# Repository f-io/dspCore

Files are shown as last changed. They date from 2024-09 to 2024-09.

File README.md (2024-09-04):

# dspCore
Build arround the ADAU1452 / ADAU1462 / ADAU1466 from Analog Devices with balanced 2-in / 6-out as well as support for I2S, SPDIF and TDM. This board is optimized for low noise performance and in particular to support all features of the [ICEpower 300A1](https://shop.icepoweraudio.com/product/300a1/) and similary amplifier modules.<br>

First prototyp build in 2014, redesigned in 2016 and the lastest version in 2021, mostly to substetude conflict materials like tantalum. The I2S input was tested with RaspberryPi 3/4/5 and ESP32S3.

## Design requirements
 - Balanced  2-in / 6-out 
 - Low idle noise without active mute circuit (compression driver requirement @ >100dB/1W/1m)
 - Stereo 3-way active x-over with FIR support for mid-high
 - Flexible I2S interaface
 - 48V DC batterie operation

## Hardware
dspCore

- DSP:  [ADAU1466](https://www.analog.com/en/products/adau1466.html) or [ADAU1452](https://www.analog.com/en/products/adau1452.html)
- A/D:  [CS5381](https://www.cirrus.com/products/cs5381/)
- D/A:  [CS4389](https://www.cirrus.com/products/cs4398/)
- OPA:  [OPA1612](https://www.ti.com/product/de-de/OPA1612/part-details/OPA1612AID)
- XO:   [CCHD-957](https://www.crystek.com/home/oscillator/clockdetail.aspx?pn=CCHD-957)
- USB:  [CY7C68013A](https://www.infineon.com/cms/de/product/universal-serial-bus/usb-2.0-peripheral-controllers/ez-usb-fx2lp-fx2g2-usb-2.0-peripheral-controller/cy7c68013a-56ltxc/)

## Measurements
__The Poor Engineer's Distortion Analyzer__ is a distortion analyzer based on the idea of KJBob (@ ADI EngineeringZone).<br><br>
This is a loop back measurment (DSP->D/A->A/D->DSP), the result is therefore the performance of the full chain. The readings are close to the datasheet specifications of the CS4398, which makes us confident that we are measuring the right thing, but of course there is an uncertainty without external verification.<br>

### DUT
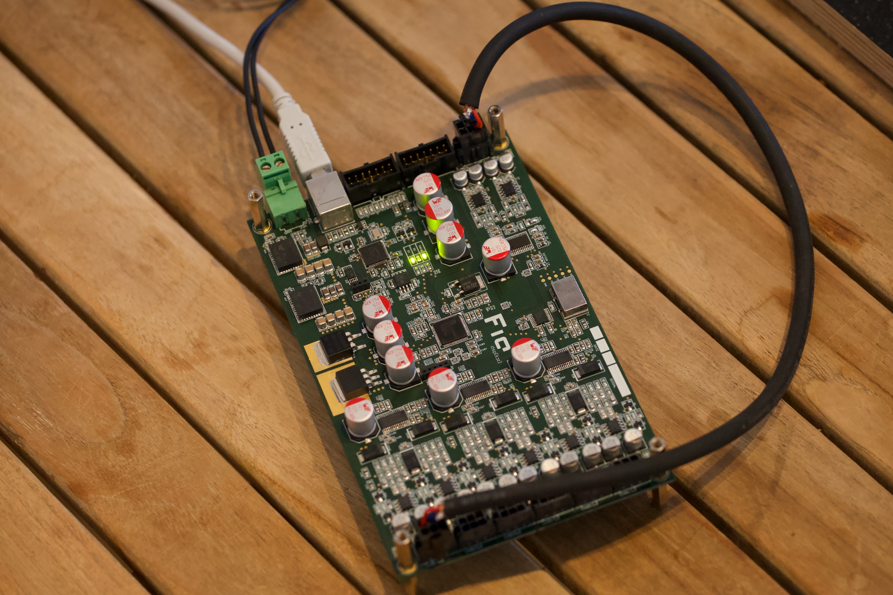
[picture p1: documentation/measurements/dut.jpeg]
dspCore
<br>

### 1V RMS
```0.000527918% THD+N = -105.54dB (a-weighted)```
<br><br>
![dspCore](documentation/measurements/1vrms_dspCore(diff)_thd+n.jpeg)<br>
### 2V RMS
```0.000626624% THD+N = -104.06dB (a-weighted)```
<br><br>
![dspCore](documentation/measurements/2vrms_dspCore(diff)_thd+n.jpeg)<br>

## To do

- Port eagle -> KiCad

## Usecase
![dspCore](documentation/images/tonkraftwerk.jpeg)<br>
![dspCore](documentation/images/tonkraftwerk_electronics.jpeg)<br>

## License

The hardware is licensed under CC BY-SA 4.0

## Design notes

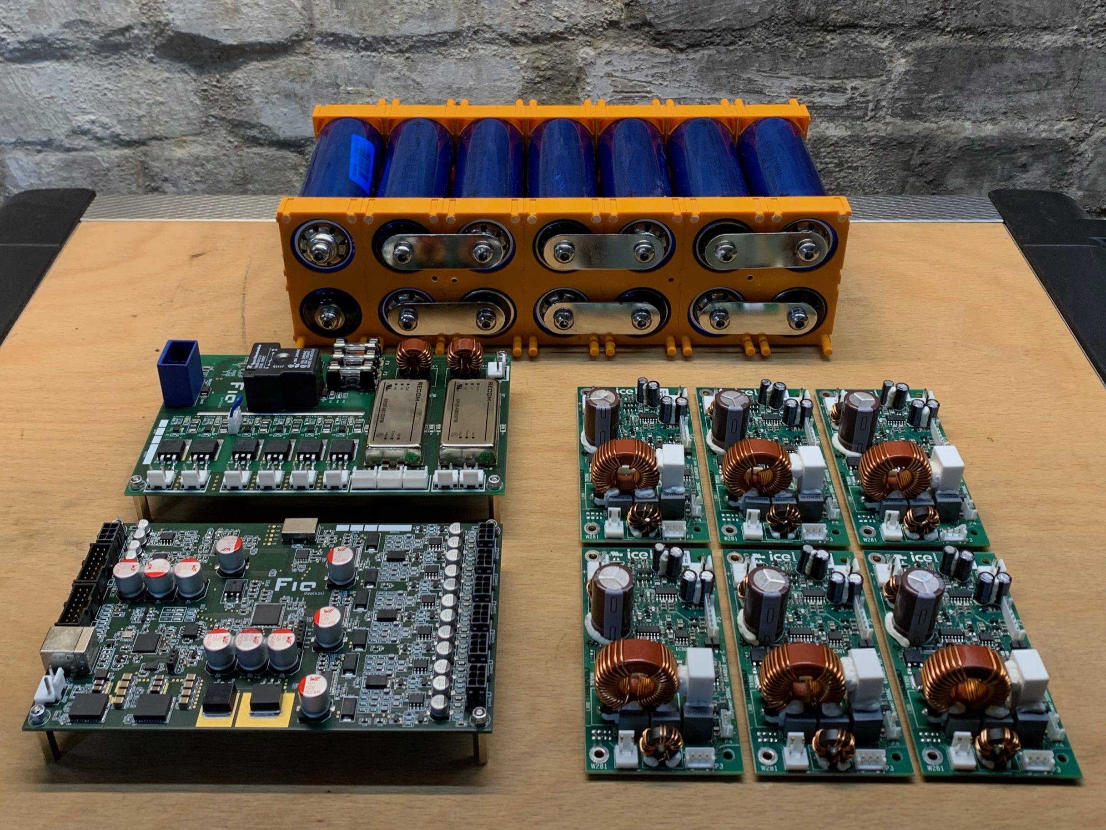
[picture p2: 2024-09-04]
documentation/images/tonkraftwerk_electronics.jpeg

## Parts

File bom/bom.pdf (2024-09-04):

Quantity | Value | Package | Part | Manufacturer | PartNr. Mouser
C
7 | 15p | C-0603 | C32, C43, C110, C125, C139, C141, C182 | Murata | 81-GRM39C150F50
1 | 150p | C-0603 | C115 | Murata | 81-GRM1885C1H151GA
4 | 470p | C-0603 | C3, C27, C40, C58 | Murata | 81-GRM39C471F50
12 | 2200p | C-0805 | C22, C29, C64, C67, C89, C96, C127, C138, C166, C170, C201, C204 | Murata | 81-GRM2165C1H222FA1D
2 | 2700p | C-0603 | C14, C51 | Murata | 81-GRM1885C1H272GA1D
1 | 5600p | C-0603 | C114 | Kemet | 80-C0603C562F3G
12 | 6800p | C-0805 | C23, C34, C65, C69, C90, C100, C130, C144, C167, C174, C202, C206 | Murata | 81-GRM2195C1H682FA1D
37 | 0.01u | C-0603 | C1, C2, C5, C17, C19, C24, C30, C31, C35, C44, C47, C48, C52, C53, C54, C61, C79, C93, C97, C98, C102, C105, C109, C111, C113, C117, C122, C131, C132, C171, C172, C183, C187, C191, C195, C213, C214 | Murata | 81-GRM18R71H103JA01D
12 | 0.015u | C-0805 | C21, C28, C63, C66, C88, C95, C126, C137, C165, C169, C200, C203 | Murata | 81-GRM2195C1H153GA1D
12 | 0.018u | C-0805 | C9, C37, C55, C72, C82, C106, C118, C150, C155, C177, C192, C211 | Murata | 81-GRM21B5C1H183GA1L
45 | 0.10u | C-0603 | C7, C11, C12, C13, C15, C16, C33, C42, C50, C62, C68, C75, C84, C85, C86, C87, C91, C99, C101, C103, C108, C120, C121, C123, C128, C129, C133, C135, C136, C140, C142, C143, C147, C152, C153, C157, C158, C159, C160, C161, C173, C175, C176, C197, C205 | Murata | 81-GRM188R71H104JA3D
1 | 0.22u | C-0603 | C196 | Murata | 81-GRM188R71H224KA4D
15 | 1u | C-0603 | C6, C8, C18, C20, C36, C39, C46, C49, C59, C80, C81, C104, C148, C149, C154 | Murata | 81-GRM188R71E105KA2D
5 | 4.7u | C-1206 | C179, C185, C186, C190, C194 | Maruta | 81-GRM31CR71H475KA2L
5 | 10u | C-0805 | C74, C94, C116, C124, C134 | Maruta | 81-GRM21BR71A106KE51
4 | 10u | CPOL-C | C4, C26, C41, C57 | Nichicon | 647-UUQ1V100MCL1GB
8 | 22u | C-1210 | C180, C181, C188, C189, C198, C199, C207, C208 | Maruta | 81-GRM32ER61E226KE15
9 | 33u | CPOL-CT7343 | C25, C45, C71, C92, C112, C146, C168, C184, C210 | Panasonic | 667-EEF-HX1C330R
12 | 47u | CPOL-D | C10, C38, C56, C73, C83, C107, C119, C151, C156, C178, C193, C212 | Nichicon | 647-UUQ1C470MCL1GB
10 | 100u | CPOL-G | C60, C70, C76, C77, C78, C145, C162, C163, C164, C209 | WE | 710-875075561005

Quantity | Value | Package | Part | Manufacturer | PartNr. Mouser
R
6 | 33R | 741-8_S | RN1, RN2, RN3, RN4, RN5, RN6 | CTS | 774-741X083330JP
2 | 33R | R-0603 | R19, R49 | Vishay | 594-MCT06030C3309FP5
4 | 91R | R-0603 | R8, R12, R31, R34 | Vishay | 71-TNPW060390R9BEEA
15 | 196R | R-0603 | R9, R22, R37, R45, R54, R63,R65, R71, R76, R80, R95, R111, R122, R132, R142 | Vishay | 71-TNPW0603196RBEEA
12 | 316R | R-0603 | R11, R24, R39, R47, R56, R66, R82, R98, R113, R124, R134, R144 | Vishay | 71-TNPW0603316RBEEA
12 | 464R | R-0603 | R15, R21, R42, R44, R58, R60, R88, R92, R116, R121, R137, R140 | Vishay | 71-TNPW0603464RBEEA
4 | 634R | R-0603 | R3, R18, R26, R40 | Panasonic | 667-ERA-3AEB6340V
13 | 681R | R-0603 | R10, R23, R38, R46, R55, R64, R81, R96, R105, R112, R123, R133, R143 | Vishay | 71-TNPW0603681RBEEA
2 | 1k | R-0603 | R61, R103 | Vishay | 594-MCT06030C1001FP5
9 | 2k | R-0603 | R2, R30, R51, R68, R73, R75, R102, R127, R147 | Vishay | 594-MCT06030C2001FP5
1 | 4k3 | R-0603 | R85 | Vishay | 71-TNPW06034K30BEEA
7 | 5k | R-0603 | R1, R25, R48, R69, R99, R125, R145 | Vishay | 71-CRCW0603-4.99K-E3
28 | 10k | R-0603 | R5, R7, R13, R17, R29, R33, R36, R53, R62, R67, R70, R74, R78, R79, R83, R84, R89, R90, R93, R94, R97, R100, R106, R109, R114, R119, R129, R150 | Vishay | MCT06030C1002FP500
1 | 22k | R-0603 | R130 | Vishay | 71-CRCW0603-22K-E3
2 | 40k2 | R-0603 | R108, R138 | Vishay | 71-CRCW0603-40.2K-E3
3 | 84k5 | R-0603 | R110, R148, R149 | Vishay | 71-CRCW0603-84.5K-E3
30 | 100k | R-0603 | R4, R6, R14, R16, R20, R27, R28, R32, R35, R41, R43, R50, R52, R57, R59, R72, R77, R86, R87, R91, R101, R104, R107, R115, R120, R126, R128, R136, R139, R146 | Vishay | 594-MCT06030C1003FP5
2 | 174k | R-0603 | R131, R135 | Vishay | 71-CRCW0603-174K-E3
1 | 267k | R-0603 | R141 | Vishay | 71-CRCW0603-267K-E3
1 | 1M | R-0603 | R117 | Vishay | 71-CRCW0603-1.0M-E3
| L
19 | 33R | L-2012C | L1, L2, L3, L4, L5, L6, L7, L8, L9, L10, L11, L12, L13, L14, L15, L16, L17, L18, L19 | Laird | 875-HZ0805E601R-10

Quantity | Value | Package | Part | Manufacturer | PartNr. Mouser
IC
1 | 24.576MHz | CCHD-957 | Y1/Y2 | Crystek | 549-CCHD-957-25-24.5
1 | 24.000MHz | 3.2X2.5MM | Y3 | Epson | 732-TX325-24F20G-AC3
1 | 24AA256ST | TSSOP8 | IC6 | Microchip | 579-24AA256T-I/ST
1 | 25AA1024 | SO-08M | IC2 | Microchip | 579-25AA1024T-I/SM
7 | 2SC3326 | SOT-23 | Q2, Q4, Q6, Q10, Q13, Q15, Q17 | Toshiba | 757-2SC3326-BLF
7 | MMUN2111LT1 | SOT-23 | Q1, Q3, Q5, Q9, Q12, Q14, Q16 | ON | 863-MMUN2111LT1G
2 | MMBT2222A | SOT-23 | Q8, Q11 | Fairchild | 512-MMBT2222A
1 | ADAU1452 | LFCSP-72 | IC1 | ADI | 584-ADAU1452WBCPZ
3 | CS4398 | TSSOP-28 | U5, U9, U12 | Cirrus | 777-CS4398-CZZ
1 | CS5381 | TSSOP-24 | U3 | Cirrus | 777-CS5381-KZZ
1 | CY7C68013A-56LTXC | QFN56 | IC3 | Cypress | 727-CY7C68013A56LTXC
2 | ADM811 | SOT143 | IC4, IC5 | ADI | 584-ADM811TARTZ-R7
3 | LNJ337W83RA | LED 0603 GR | D1, D2, D3 | Panasonic | 667-LNJ337W83RA
8 | OPA1612AID | SOIC8 | U1, U2, U6, U7, U8, U10, U11, U13 | Ti | 595-OPA1612AIDR
1 | LMZ34002RKGR | B1QFN-41 | U17 | Ti | 595-LMZ34002RKGT
1 | LMZ35003RKGR | B1QFN-41 | U16 | Ti | 595-LMZ35003RKGT
1 | MC7805AC2T | TO263-2 | U14 | ON | 863-MC7805ACD2TR4G
1 | LM1084ISX-3.3 | TO263-3 | U15 | Ti | 926-LM1085ISX3.3NOPB
1 | SI53365 | TSSOP16 | U4 | Silicon L | 634-SI53365-B-GTR
1 | WE-TVS_824011 | SOT23-5L | D4 | WE | 710-824011
1 | SMBJ51CA | SMBJ | D5 | Littlefuse | 576-SMBJ51CA

THT
1 | B02P-NV | | X8
2 | M07X2 | | JP1, JP2 | Molex | 538-90130-1214 (http://www.mouser.de/Search/ProductDetail.aspx?qs=kEwmkoUtv7TM5CwnDLn64w%3D%3D)
7 | 43045-0612 | | X1, X2, X3, X4, X5, X7, X9 | Molex | 538-43045-0612
1 | WERI 61400416121 | USB-B | X6 | WE | 710-61400416121

194 OA-COUNT
81 PART-COUNT

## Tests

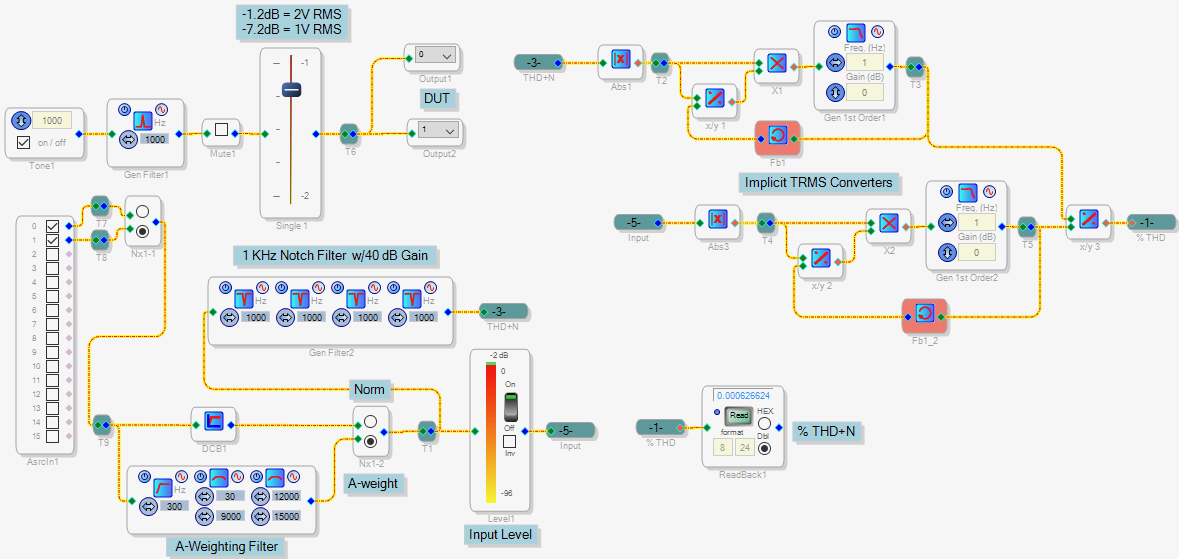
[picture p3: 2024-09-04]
documentation/measurements/2vrms_dspCore(diff)_thd+n.jpeg

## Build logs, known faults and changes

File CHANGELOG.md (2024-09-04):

# Changelog

All notable changes to this project will be documented in this file.

## [1.3] 20240828

- Initial public release

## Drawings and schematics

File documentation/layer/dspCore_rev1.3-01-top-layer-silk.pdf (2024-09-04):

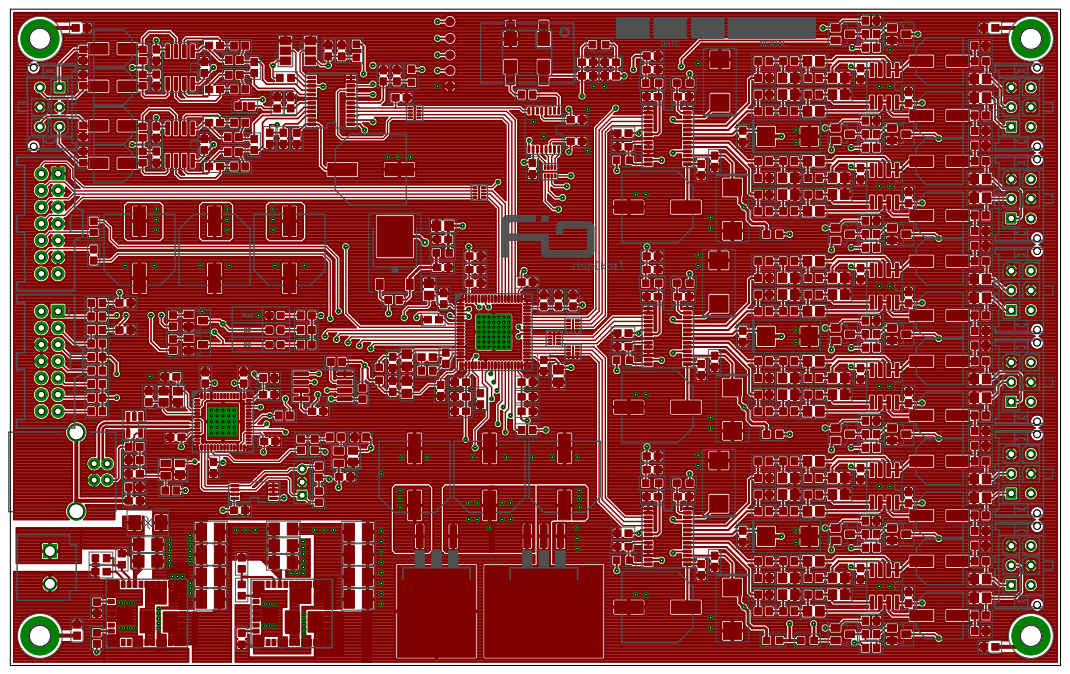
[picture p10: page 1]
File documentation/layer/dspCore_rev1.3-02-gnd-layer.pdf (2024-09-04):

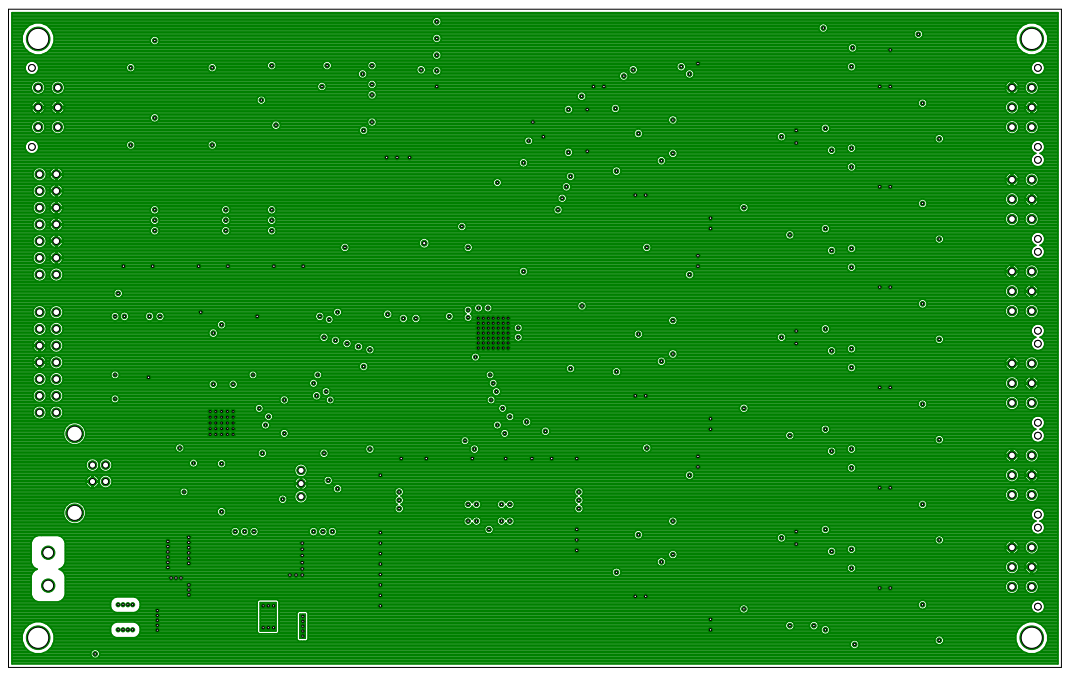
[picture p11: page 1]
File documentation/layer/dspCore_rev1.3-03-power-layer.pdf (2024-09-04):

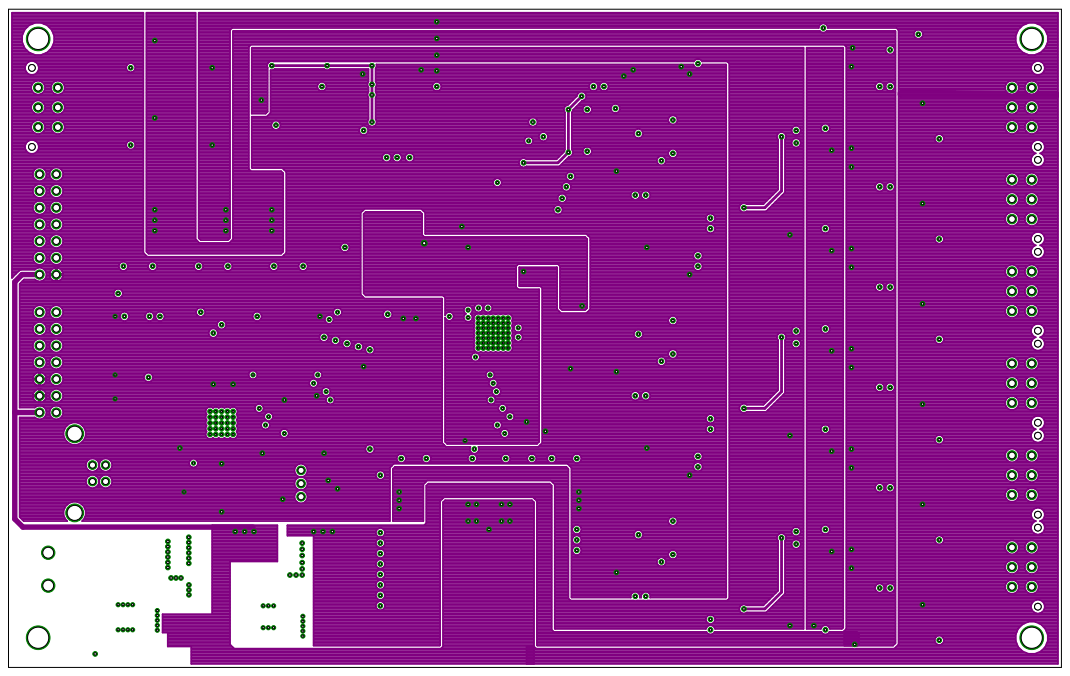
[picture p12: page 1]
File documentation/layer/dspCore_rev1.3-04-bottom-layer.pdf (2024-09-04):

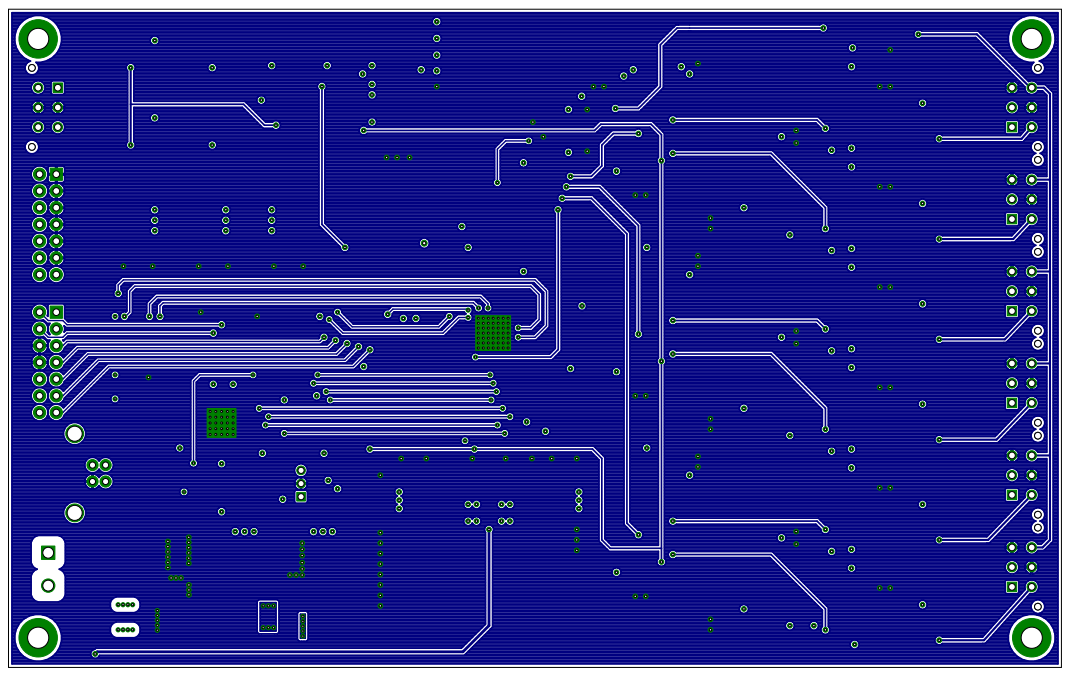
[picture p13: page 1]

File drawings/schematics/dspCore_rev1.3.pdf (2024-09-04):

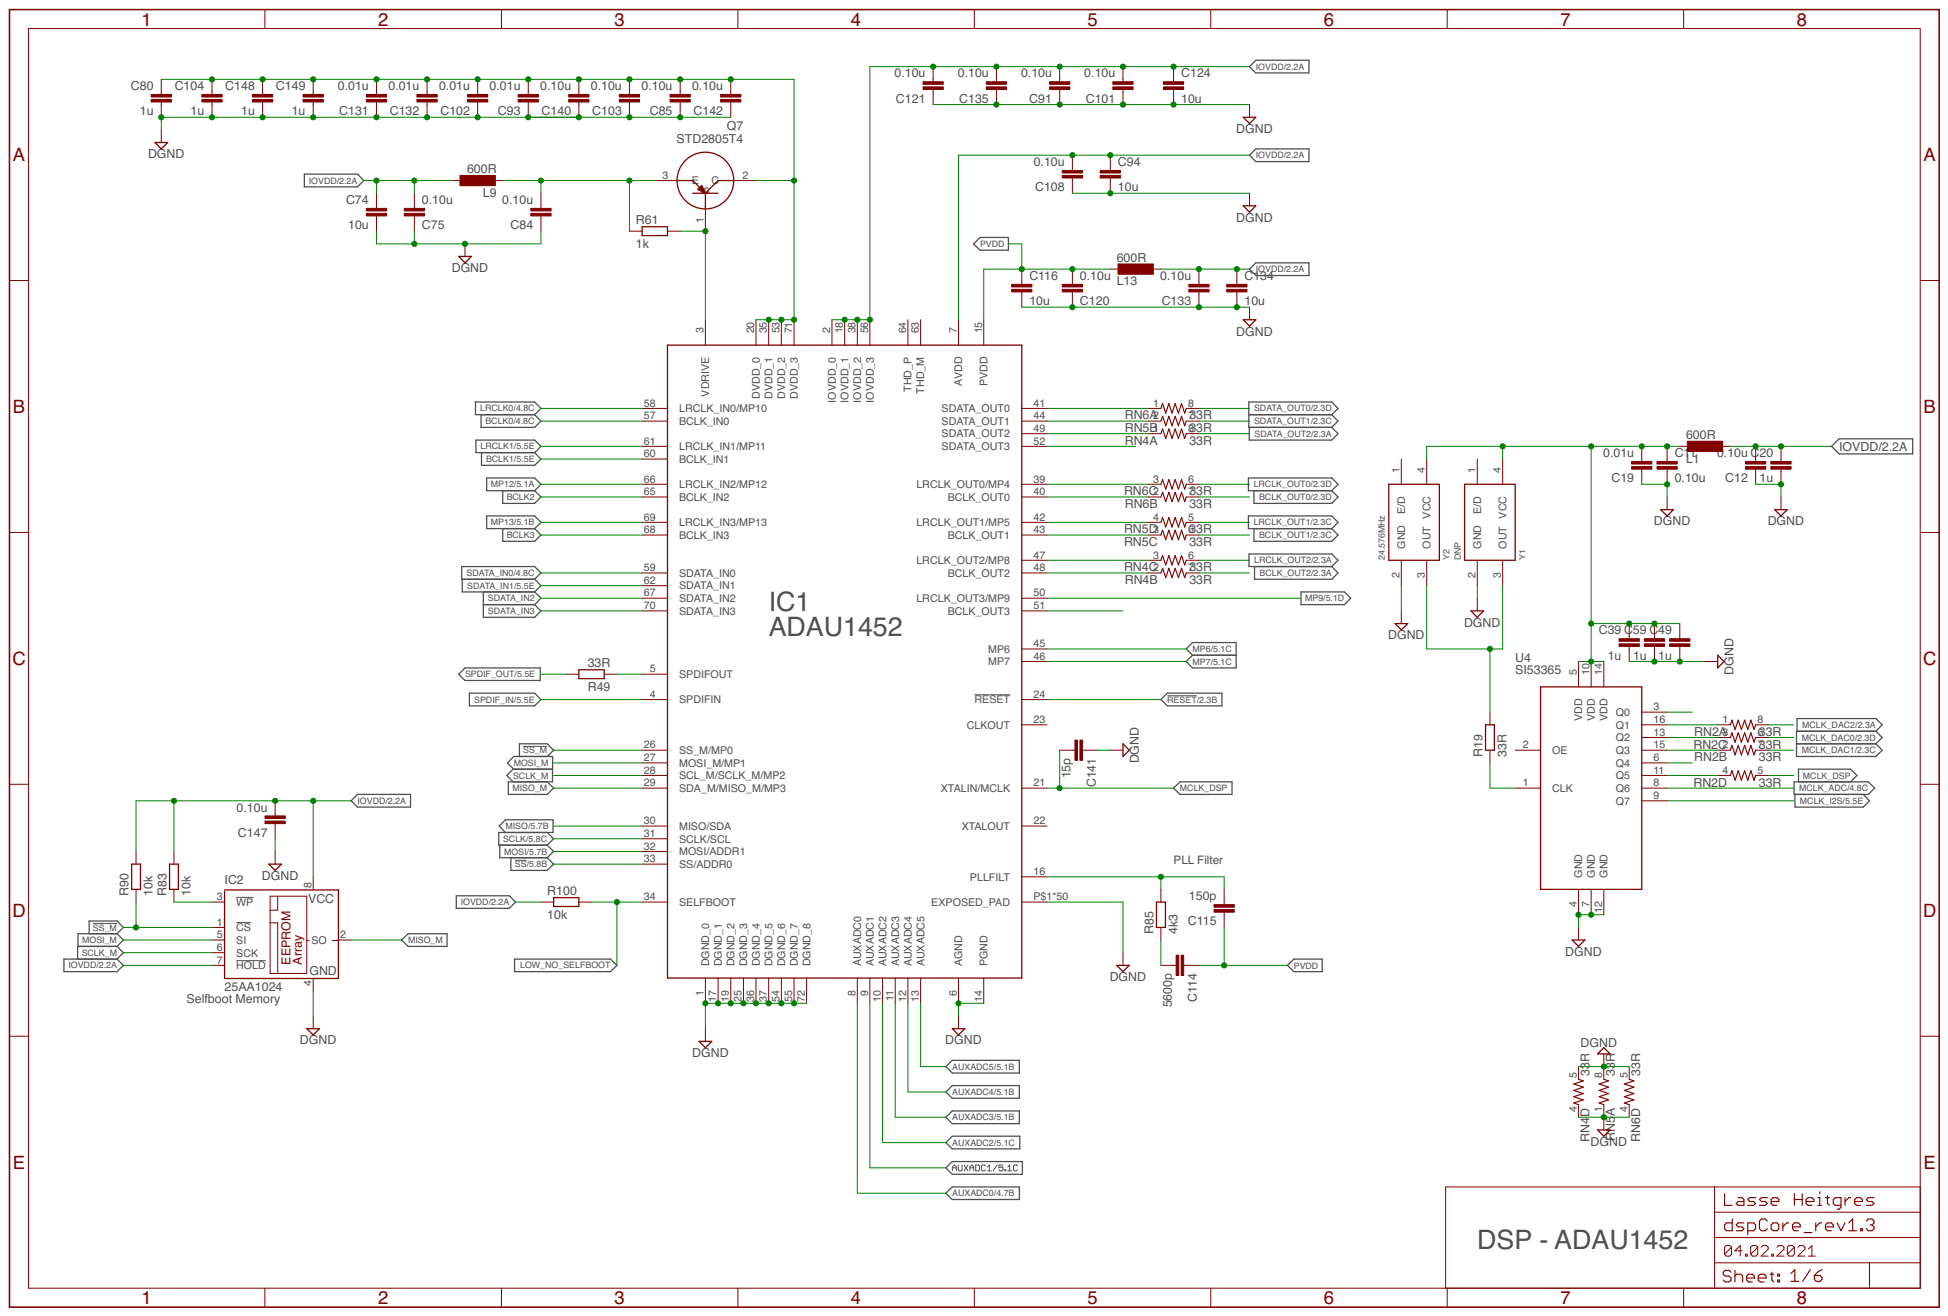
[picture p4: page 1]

BCLK2 | 42 BCLK_OUT1

SDATA_IN0/4.8C 62 | 50 BCLK_OUT3

SPDIF_IN/5.5E | CLKOUT XTALIN/MCLK | 23 RESET RESET/2.3B

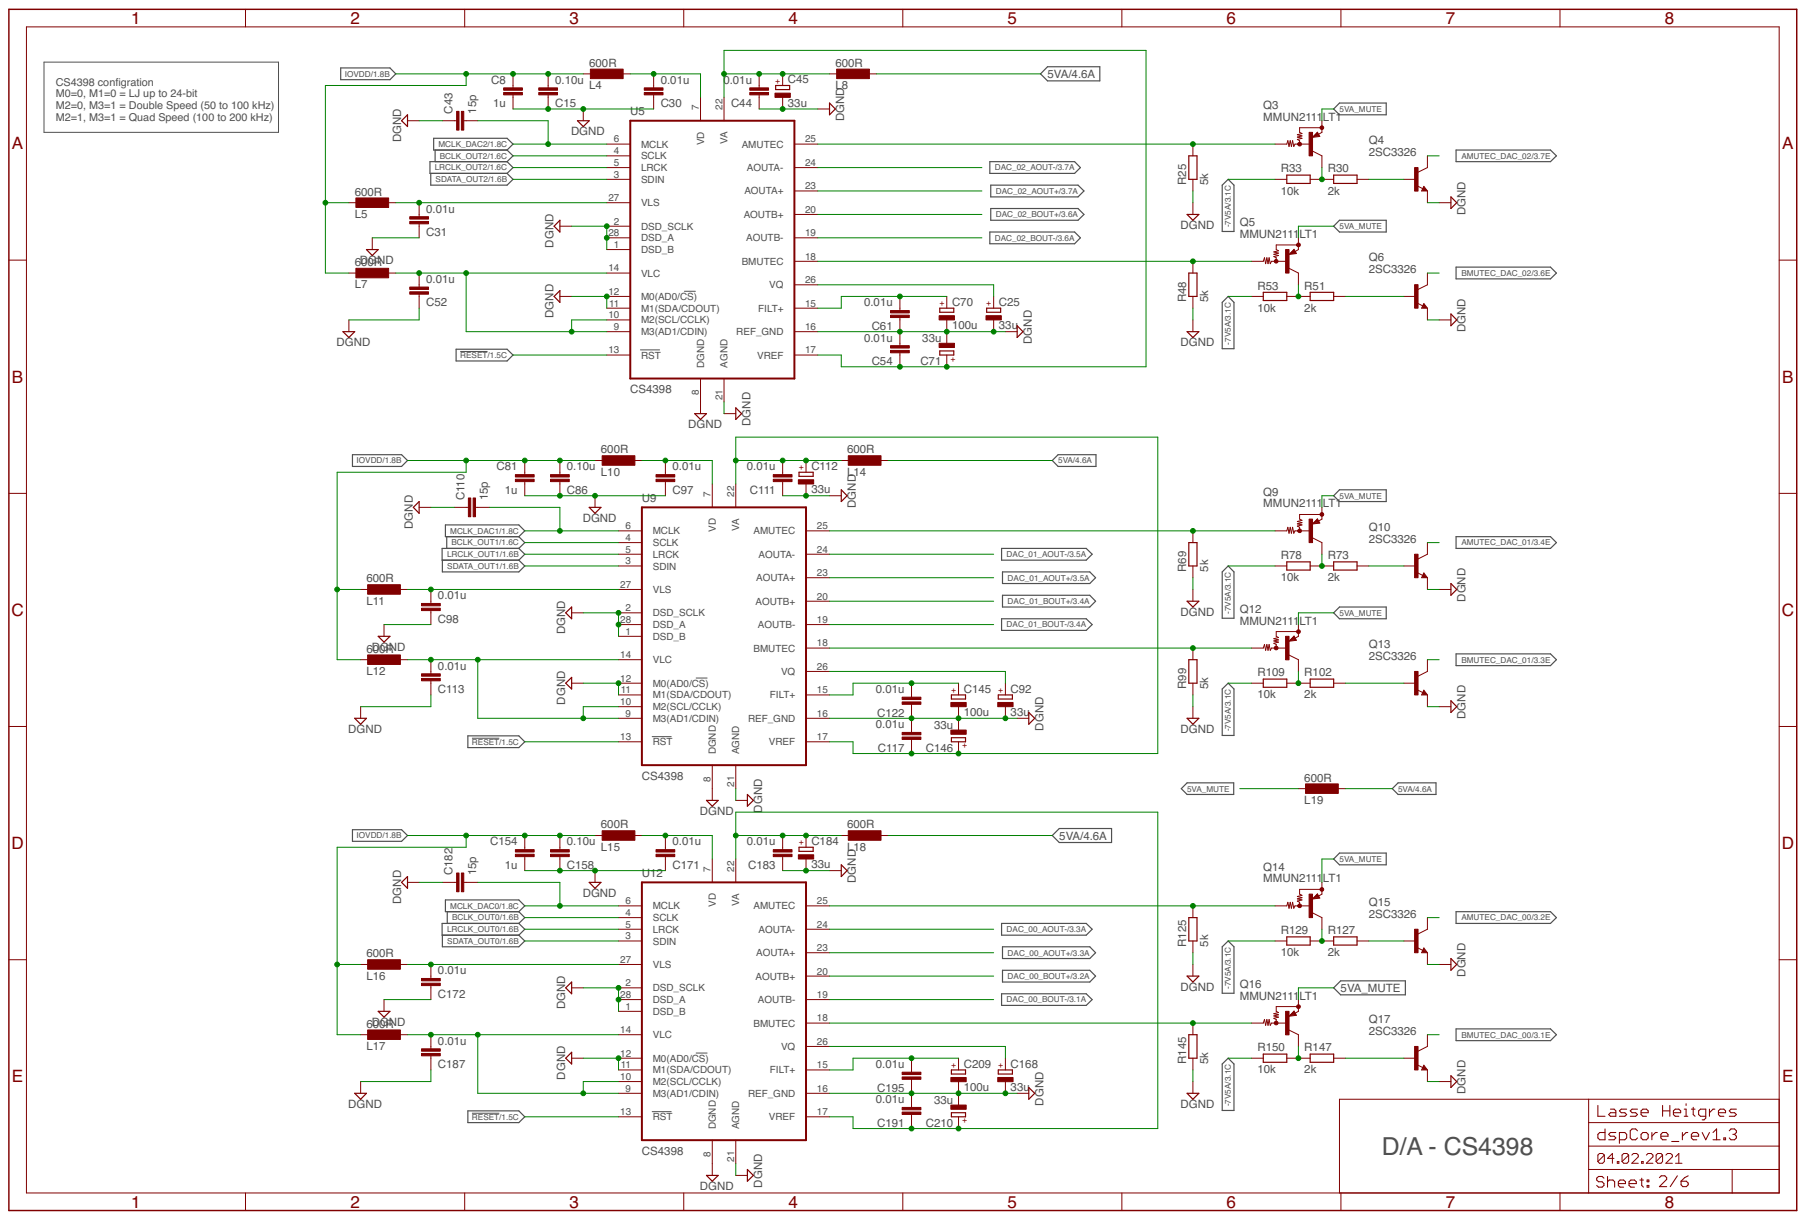
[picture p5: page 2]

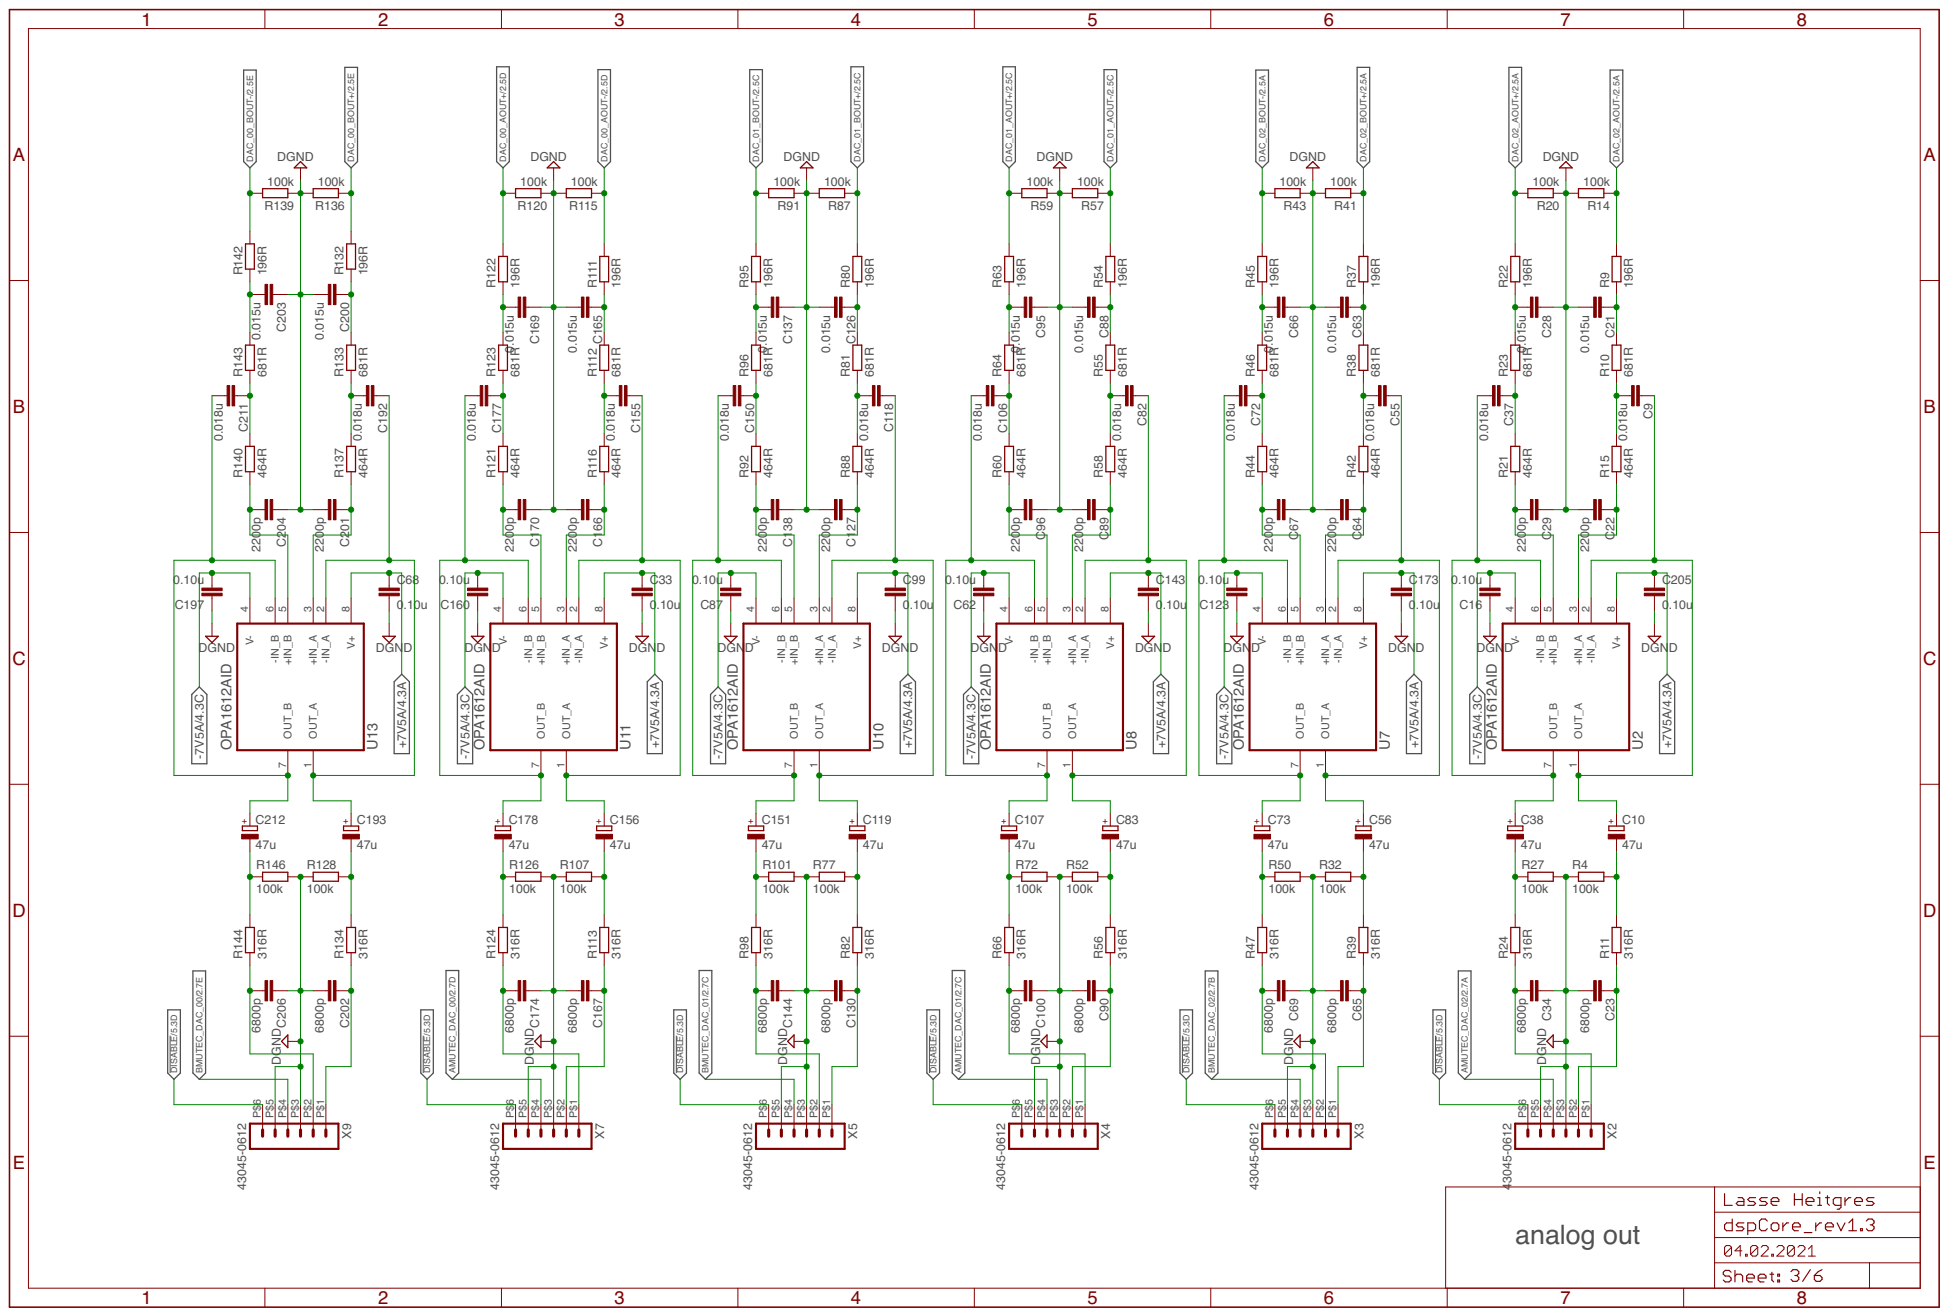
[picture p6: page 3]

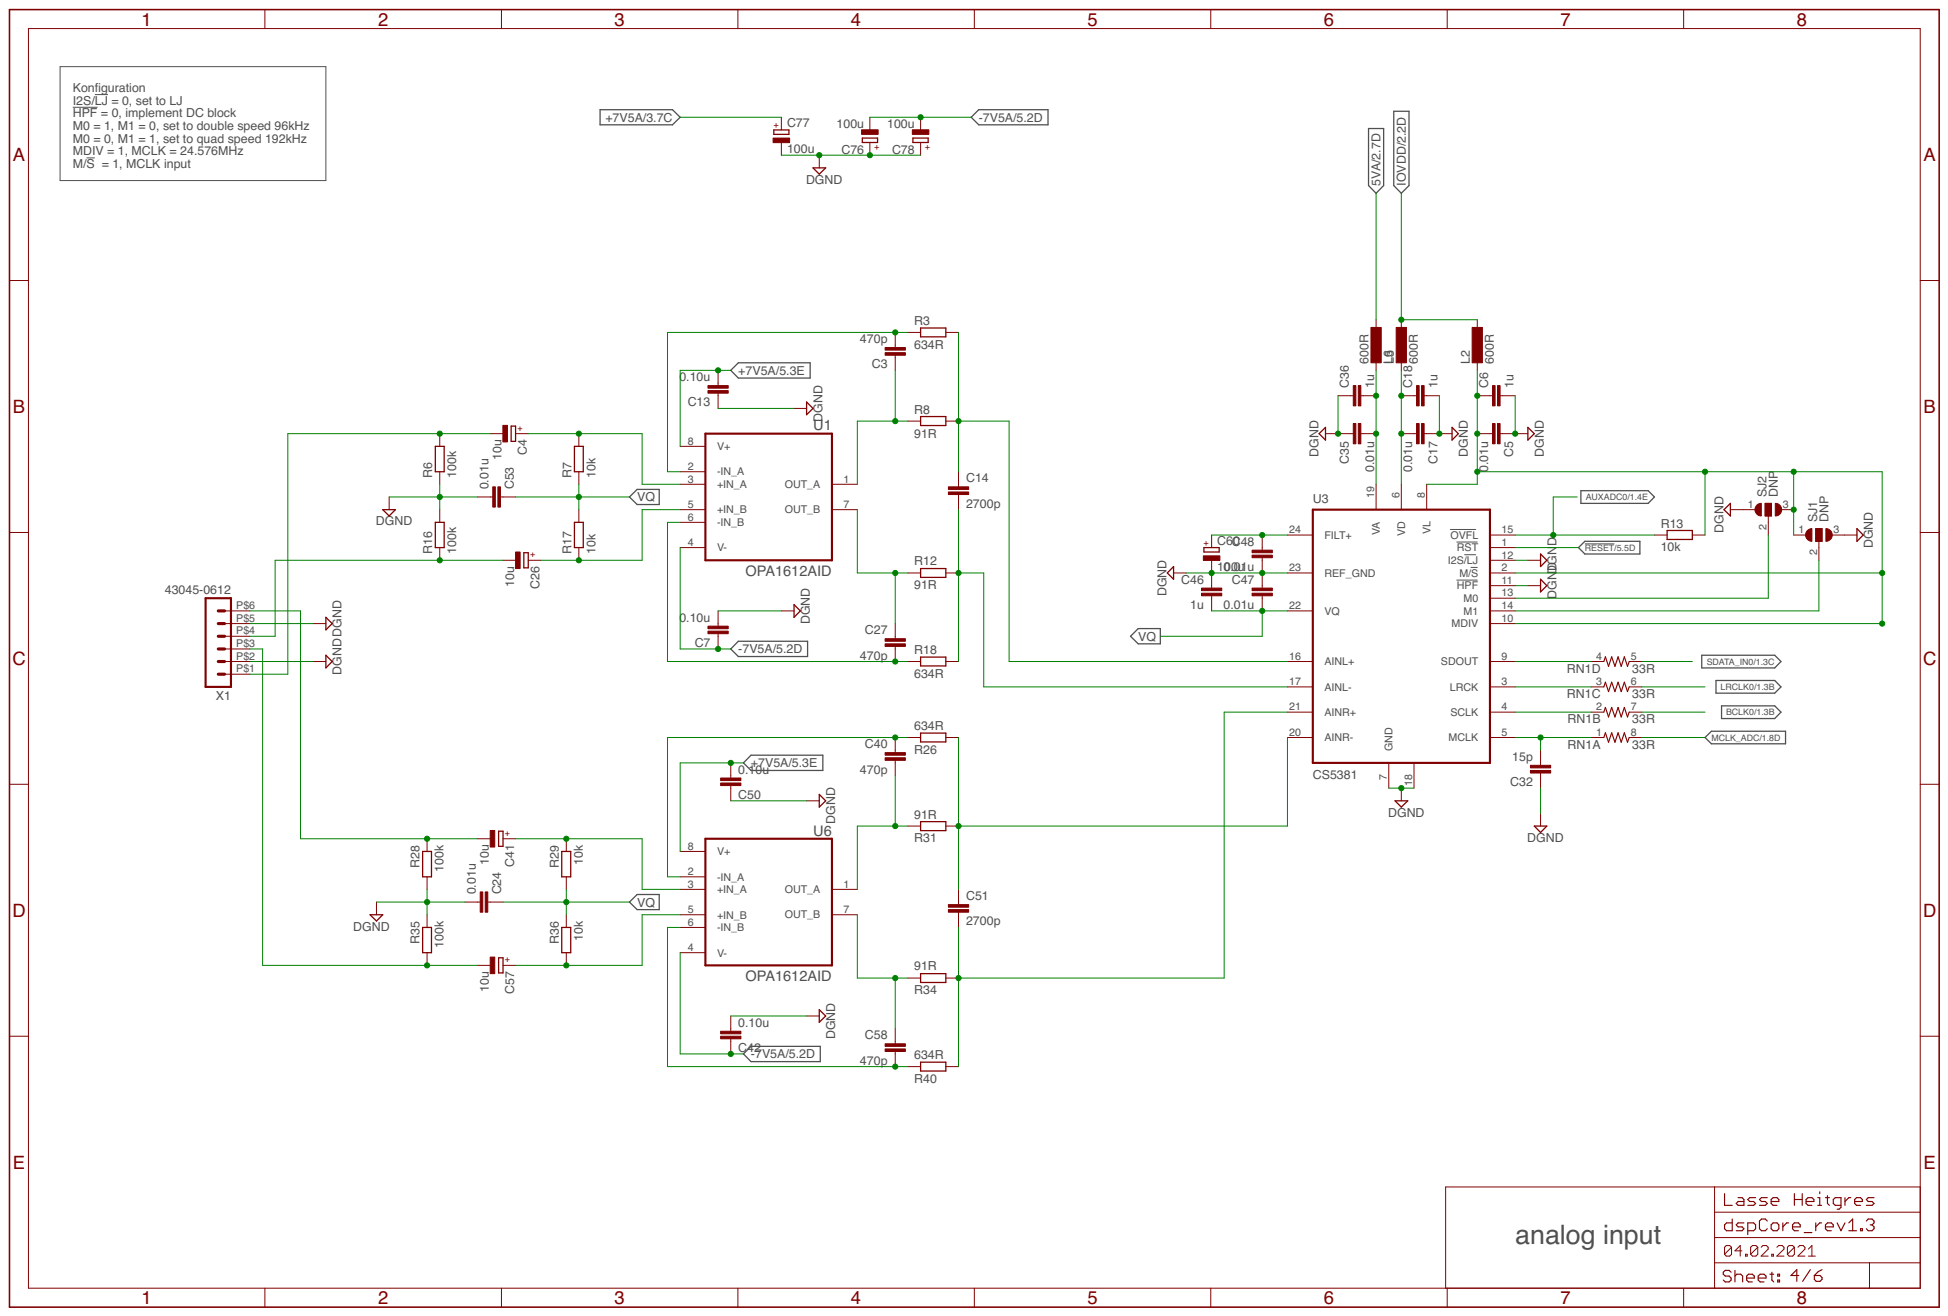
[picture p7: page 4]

Konfiguration
I2S/LJ = 0, set to LJ HPF = 0, implement DC block M0 = 1, M1 = 0, set to double speed 96kHz MDIV = 1, MCLK = 24.576MHz M/S = 1, MCLK input M0 = 0, M1 = 1, set to quad speed 192kHz

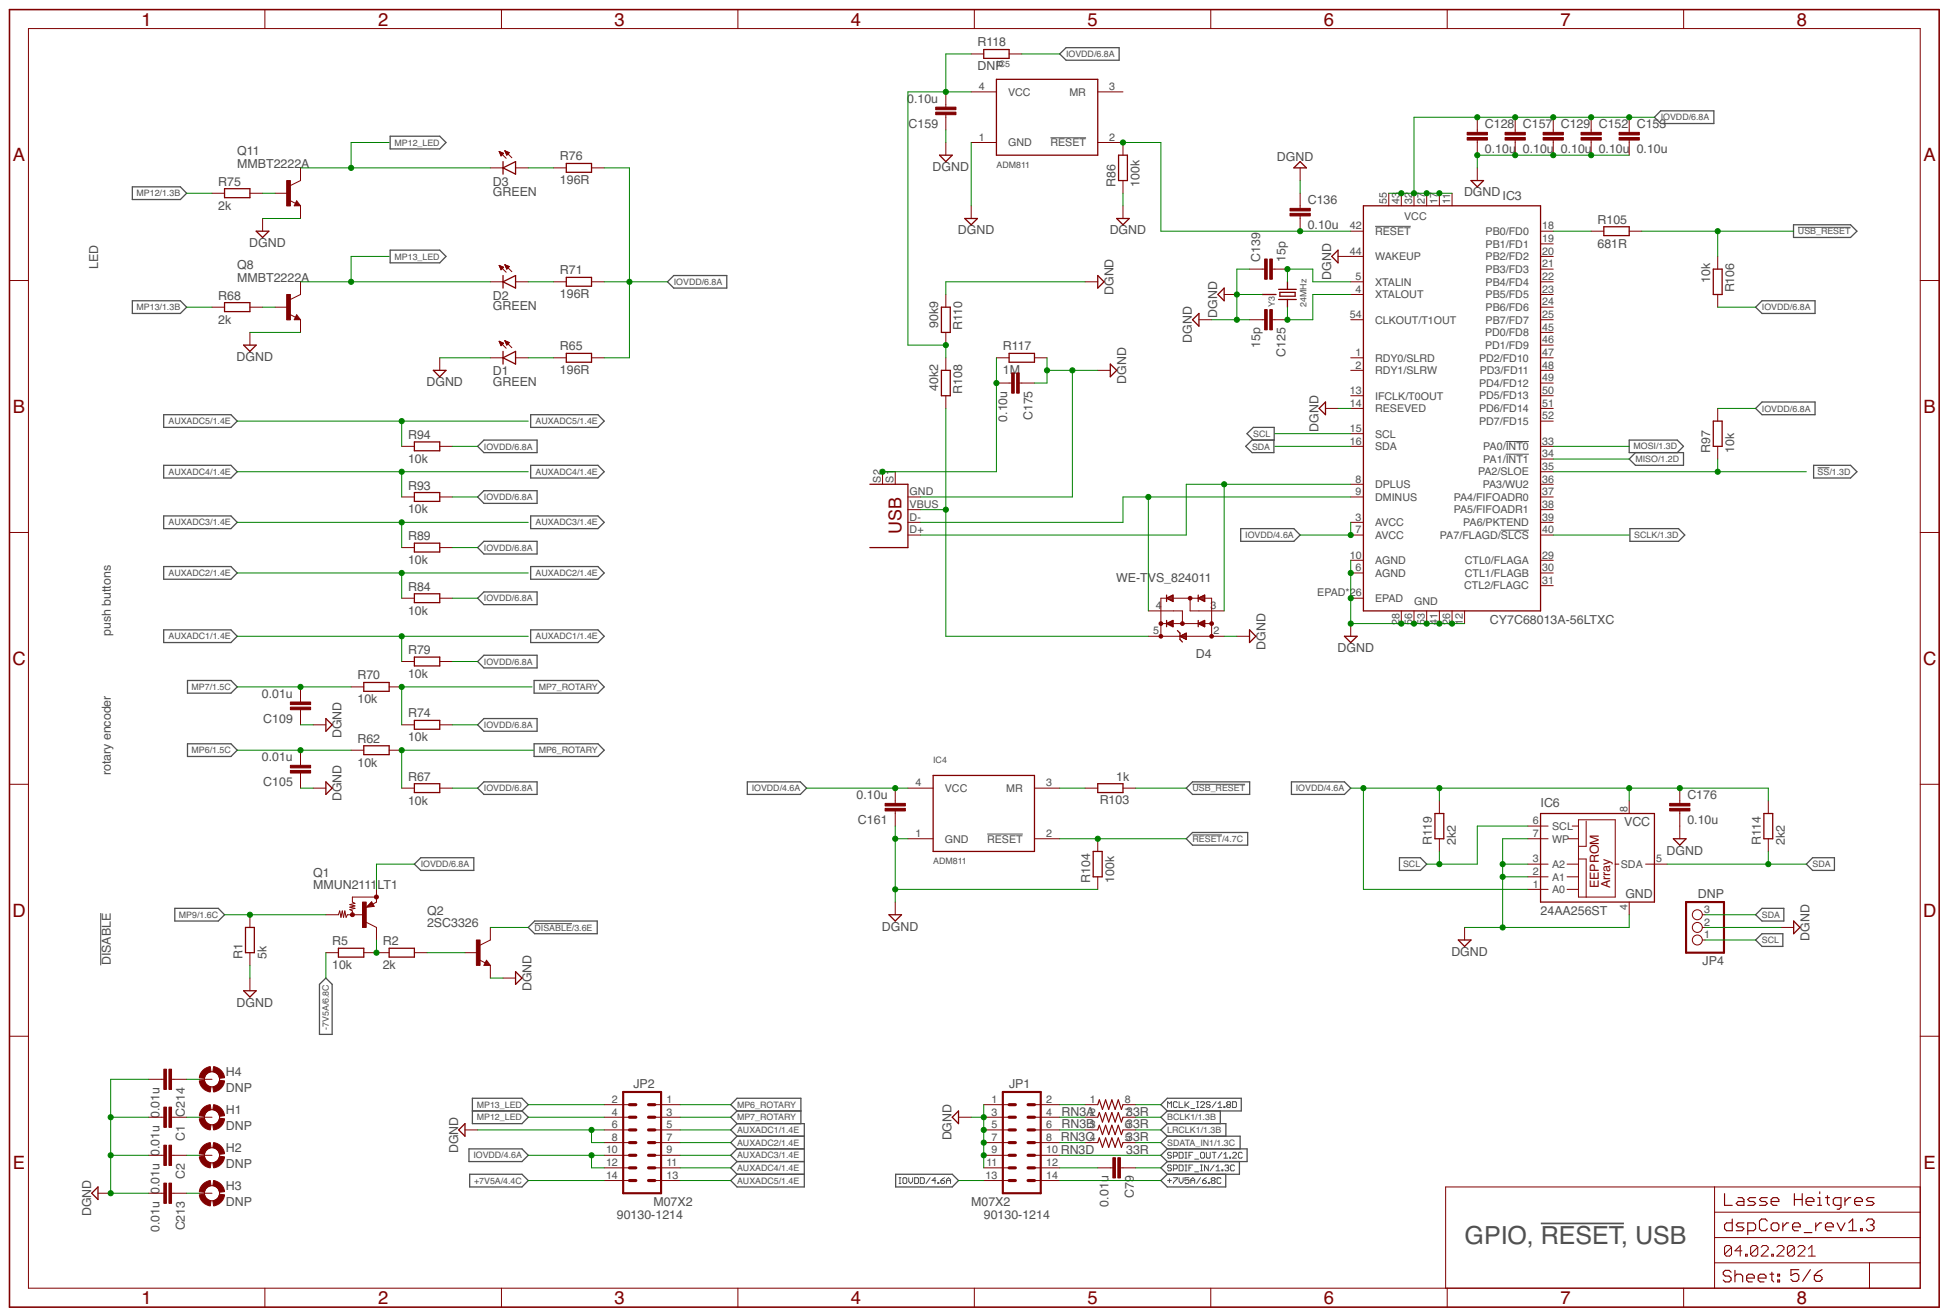
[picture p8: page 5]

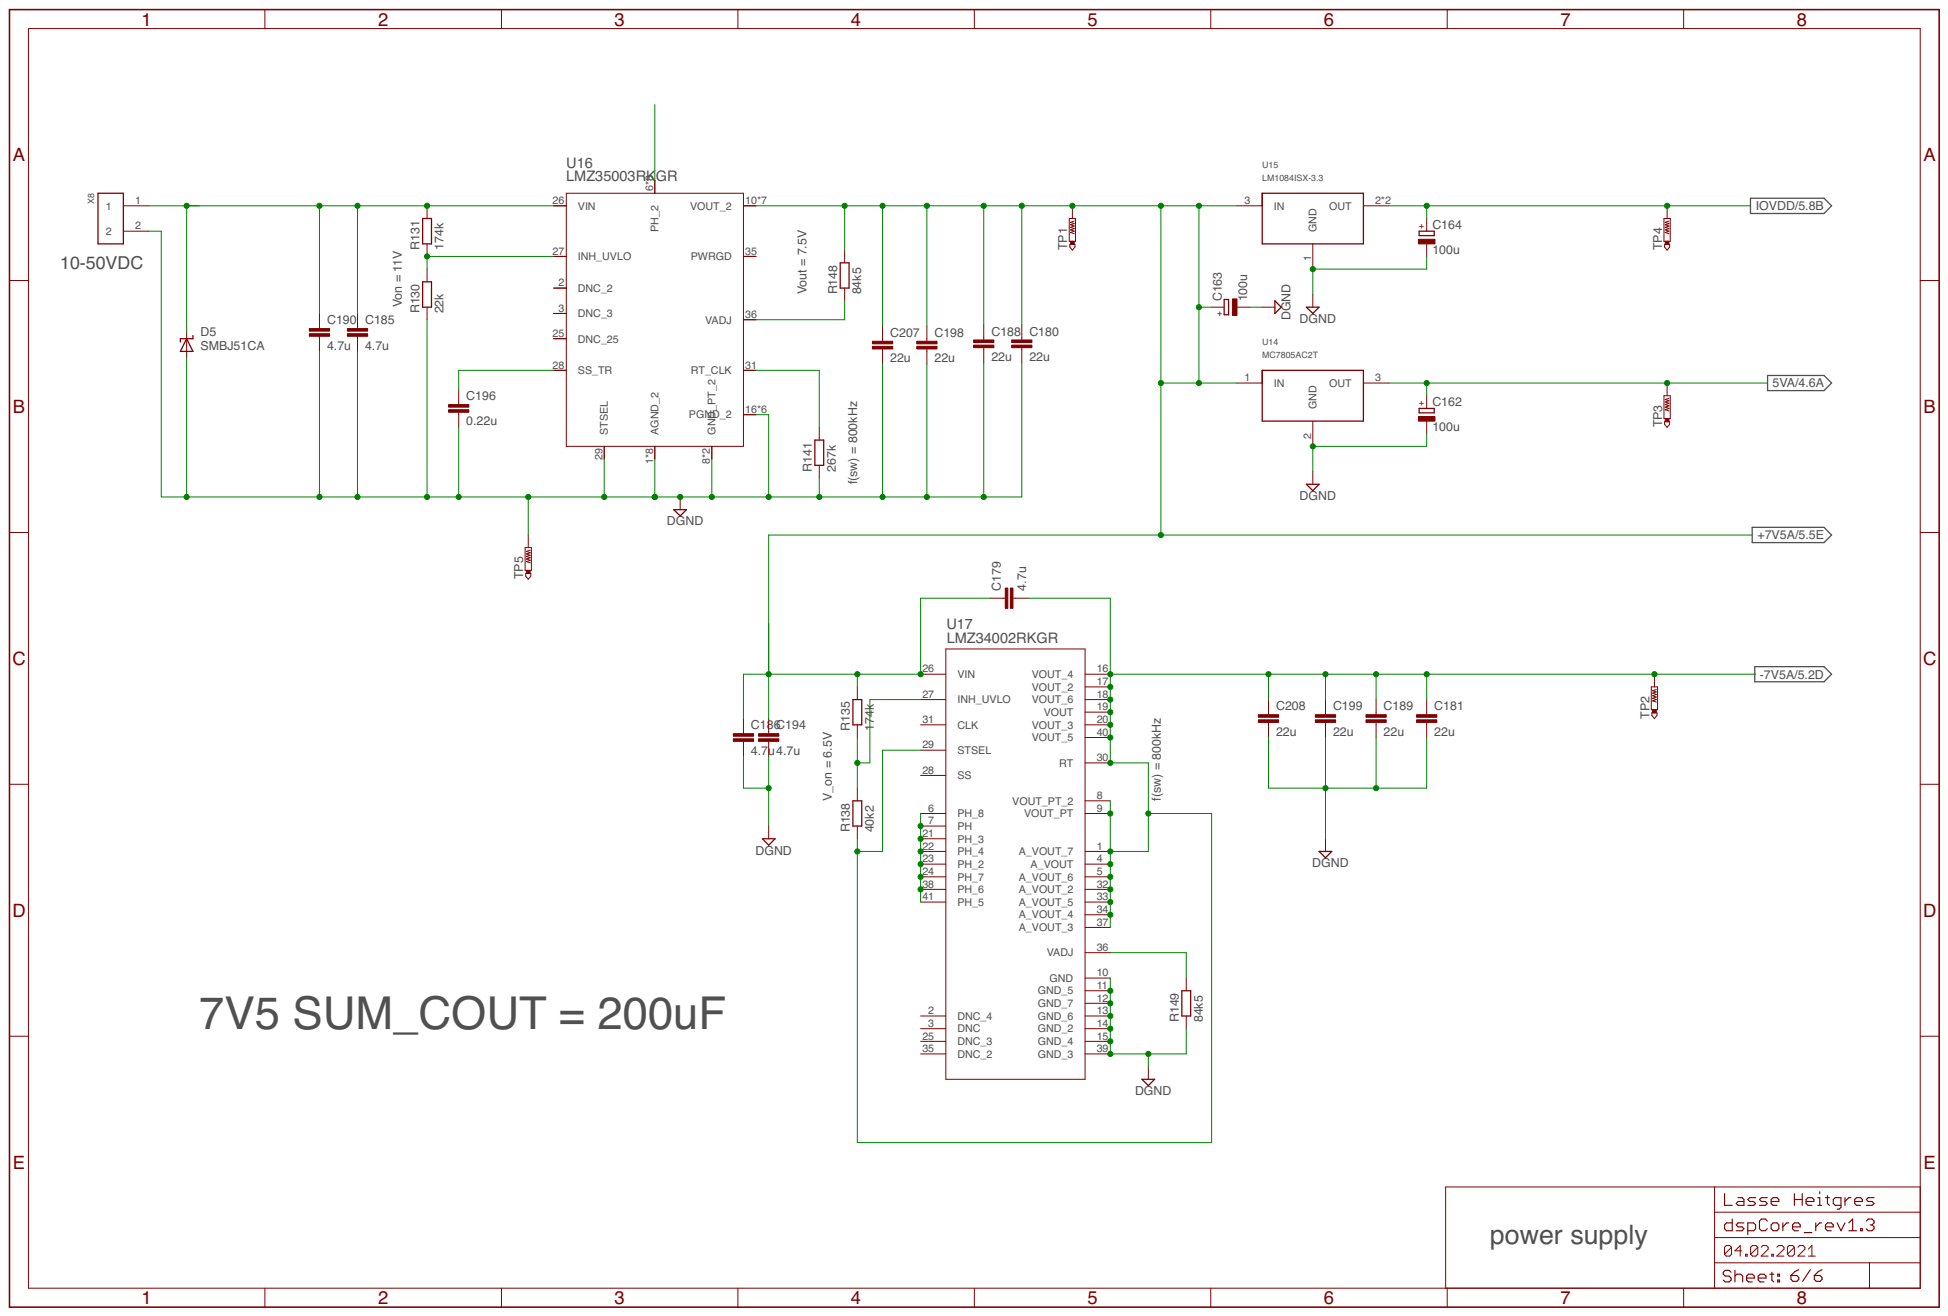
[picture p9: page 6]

23 | 4
24 | 5
38 | 32
